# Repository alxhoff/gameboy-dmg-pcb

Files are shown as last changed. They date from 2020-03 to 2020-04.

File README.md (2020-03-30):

# Gameboy DMG Raspberry Pi Board

My revived Corona project, work in progress. The idea of this board is to be a single board drop in for the Gameboy DMG case that is readily availble from all the normal places (eBay, AliExpress etc.) to provide easy game emulation using a Raspberry Pi Zero with distros such as RetroPie. The whole style of the board is that the PCB itself is self explanitory and doesn't require you to go through the schematics, something almost anyone with a bit of soldering knowledge can put together. Many features of the board can be enabled/disabled or changed using the many solder jumper pads.

The board is made in two variants:

- A cheaper to produce <100mm x <100mm board that can be very cheaply produced from manufactureres such as [JLC](https://jlcpcb.com/) and [PCBWay](https://www.pcbway.com).
- A full size (complete case utilization) board that places everything on the same motherboard

# Common components to both implementation

Both boards implement the core required features for creating a portable handheld device. The big difference is that the full size board can make use of the power switches and case cutouts that are more than 100mm from the bottom of the case, as well as being able to place the screen on the motherboard and not require a screen breakout to be used.

## Lipo charger and boost converter

The core component of a handheld device is that is can be battery powered. As such, and to avoid using prefab shields, the board has an onboard Lipo charger and battery protection that then feeds a boost converter to provide the rest of the board with the required 5V to power the RPi, screen and audio.

The Lipo charger is based around a TP4056 charger and a FS312F-G & FS8205 protection IC combo, this feeds the MT3608 boost converter. The board has two through hole battery connections where a standard single cell 4.2v Lipo battery should be connected. The front side of the PCB also has charging status SMD LEDs that can be optionally connected by jumping the appropriate jumper.

## Buttons

The board uses the standard default button layout of the Gameboy DMG also providing eight extra button connections that can be made use of through the through hole connections. The buttons are to connectied to the RPi through an MCP23017 GPIO expander, for which I will write a Linux kernel driver once the hardware is complete, it will be linked here once I am done.

## Audio

The board utilizes the PWM audio output of the RPi, providing both a simple low-pass RC filter as well as a 2.5W mono audio amplifier so that the board can actually produce a decent, and audiable, sound output. A compatible speaker 29mm 0.25W speaker should be attached to the appropriate through hole connectors.

## Screen breakout

The board utilizes the 240 x 320 ILI9341 TFT screens which are a breeze to use with Raspberry Pis through framebuffer copy drivers, such as [this](https://github.com/juj/fbcp-ili9341) one. The smaller board provides a through hole breakout where you can connect, via ribbon cable, the screen's breakout board. I am using a 2.4" screen which requires no modification to the case but larger screens can be placed with minimal modification to the case, these breakouts are available on the larger board, connecting the ribbon cable directly to the board. The larger board uses an elongated footprint to give you complete freedom as to where you solder the board along the horizonal axis.

### Small board

The small PCB provides an exact copy of the pinout found on the common LCD breakout boards such as [3.2" MSP3218](http://www.lcdwiki.com/3.2inch_SPI_Module_ILI9341_SKU:MSP3218), [2.8" MSP2807](http://www.lcdwiki.com/2.8inch_SPI_Module_ILI9341_SKU:MSP2807), [2.4" MSP2402](http://www.lcdwiki.com/2.4inch_SPI_Module_ILI9341_SKU:MSP2402), and [2.2" MSP2202](http://www.lcdwiki.com/2.2inch_SPI_Module_ILI9341_SKU:MSP2202). 

These common breakouts also provide a NPN transisor current driver circuit that allow for PWM control on the backlight. The larger board has this on the motherboard.

| Function | Header Pin | 
| --- |:---:|
| MISO | 1 | 
| BACKLIGHT/LED | 2 |  
| SCK | 3 | 
| MOSI | 4 |
| DC | 5 |
| RESET | 6 |
| CS | 7 |
| GND | 8 |
| 3.3V | 9 |

### Large board

The large board uses a header for the ribbon cable to be connected directly. The pinout is as follows. Also see the [relevant](http://www.lcdwiki.com/res/MSP3218/QD-TFT3202%20specification_v1.1.pdf) datasheets for the pinout

| Function | Header Pin | 
| --- |:---:|
| GND | 1 | 
| RESET | 2 |  
| SCK | 3 | 
| DC | 4 |
| CS | 5 |
| MOSI | 6 |
| MISO | 7 |
| GND | 8 |
| 3.3V | 9 |
| BACKLIGHT LED Anode | 10 |
| BACKLIGHT LED Cathode | 11 - 14|

# Small board

The small board must provide headers for items that are found outside of the PCB's bounds, such as power switch, power LED etc. All of the headers should be labelled as to what they do.

There are a number of labeled jumpers that enable/disable functionality of external parts such as disabling the external power switch by bridging the boost supply's outbut stright to the 5V rail.

The following jumpers can be found on the board.

| Name |Reference | Description | Default State | Notes & WARNINGS!|
| --- |:---:|---|:---:| ----- |
| Charging LEDs | JP11 | Enables the two onboard SMD LEDs that provide the status of charging from the TP4056 charger | Open |
| Connect Boost  | JP9 | Connects the battery charger/battery to the boost charger that then supplies the 5V rail | Open |
| Power switch  | JP8 | Shorts out the power switch, making the boost supply and the 5V rail always connected  | Open |
| Volume potentiometer  | JP10 & JP14 | Will fix the audio input to the PAM8302 audio amp to the differential signal between the LP audio filter's output and ground, removing ability to control volume in hardware| Open |
| PAM8302 Supply 3.3V  | JP12 | Allows for the powering of the audio amplifier from 3.3V instead of the default 5V | Open |
| PAM8302 Supply 3.3V  | JP13 | Allows for the disconnecting of the audio amplifier from its default 5V supply | Closed | NEVER should both jumpers be connects and the device powered |
| GPIO Expander I2C  | JP2 - JP4 | The GPIO expander responsible for the onboard Gameboy buttons is by default not attached to the RPi | Open |
| TFT Backlight  | JP6 & JP7 | The backlight for the LCD can be either driven by the GPIO pins (allowing PWM) or from a constant 3.3V rail, By default the screen is driven from the 3.3V rail, thus disabling PWM capabilities of the FB driver | Open & Closer respectivley | Both pins shouldn't be connected at the same time |
| RPi Audio Out  | JP1 | By default the PWM audio output of the PRi's GPIO 13 is not connected to the audio pre-amp, amp and speaker, this must be enabled by the user | Open |

# Large board

todo

## RPi header

The RPi Zero connects directly to the PCB, enough said :P

# TODO

Large board needs to be branched from small board once it is finished

## Small board/both

- Before first fab check micro USB placement.
- Expand board to provide mounting holdes for 2.4" TFT breakout.

## Large board

- Horizontal power switch in to fit the native power switch at the top of the device.
- Horizontal trim pot placement to make use of the existing screen contrast cutout.
- Screen placement to support 2.4", 2.8" and 3.2" screens.

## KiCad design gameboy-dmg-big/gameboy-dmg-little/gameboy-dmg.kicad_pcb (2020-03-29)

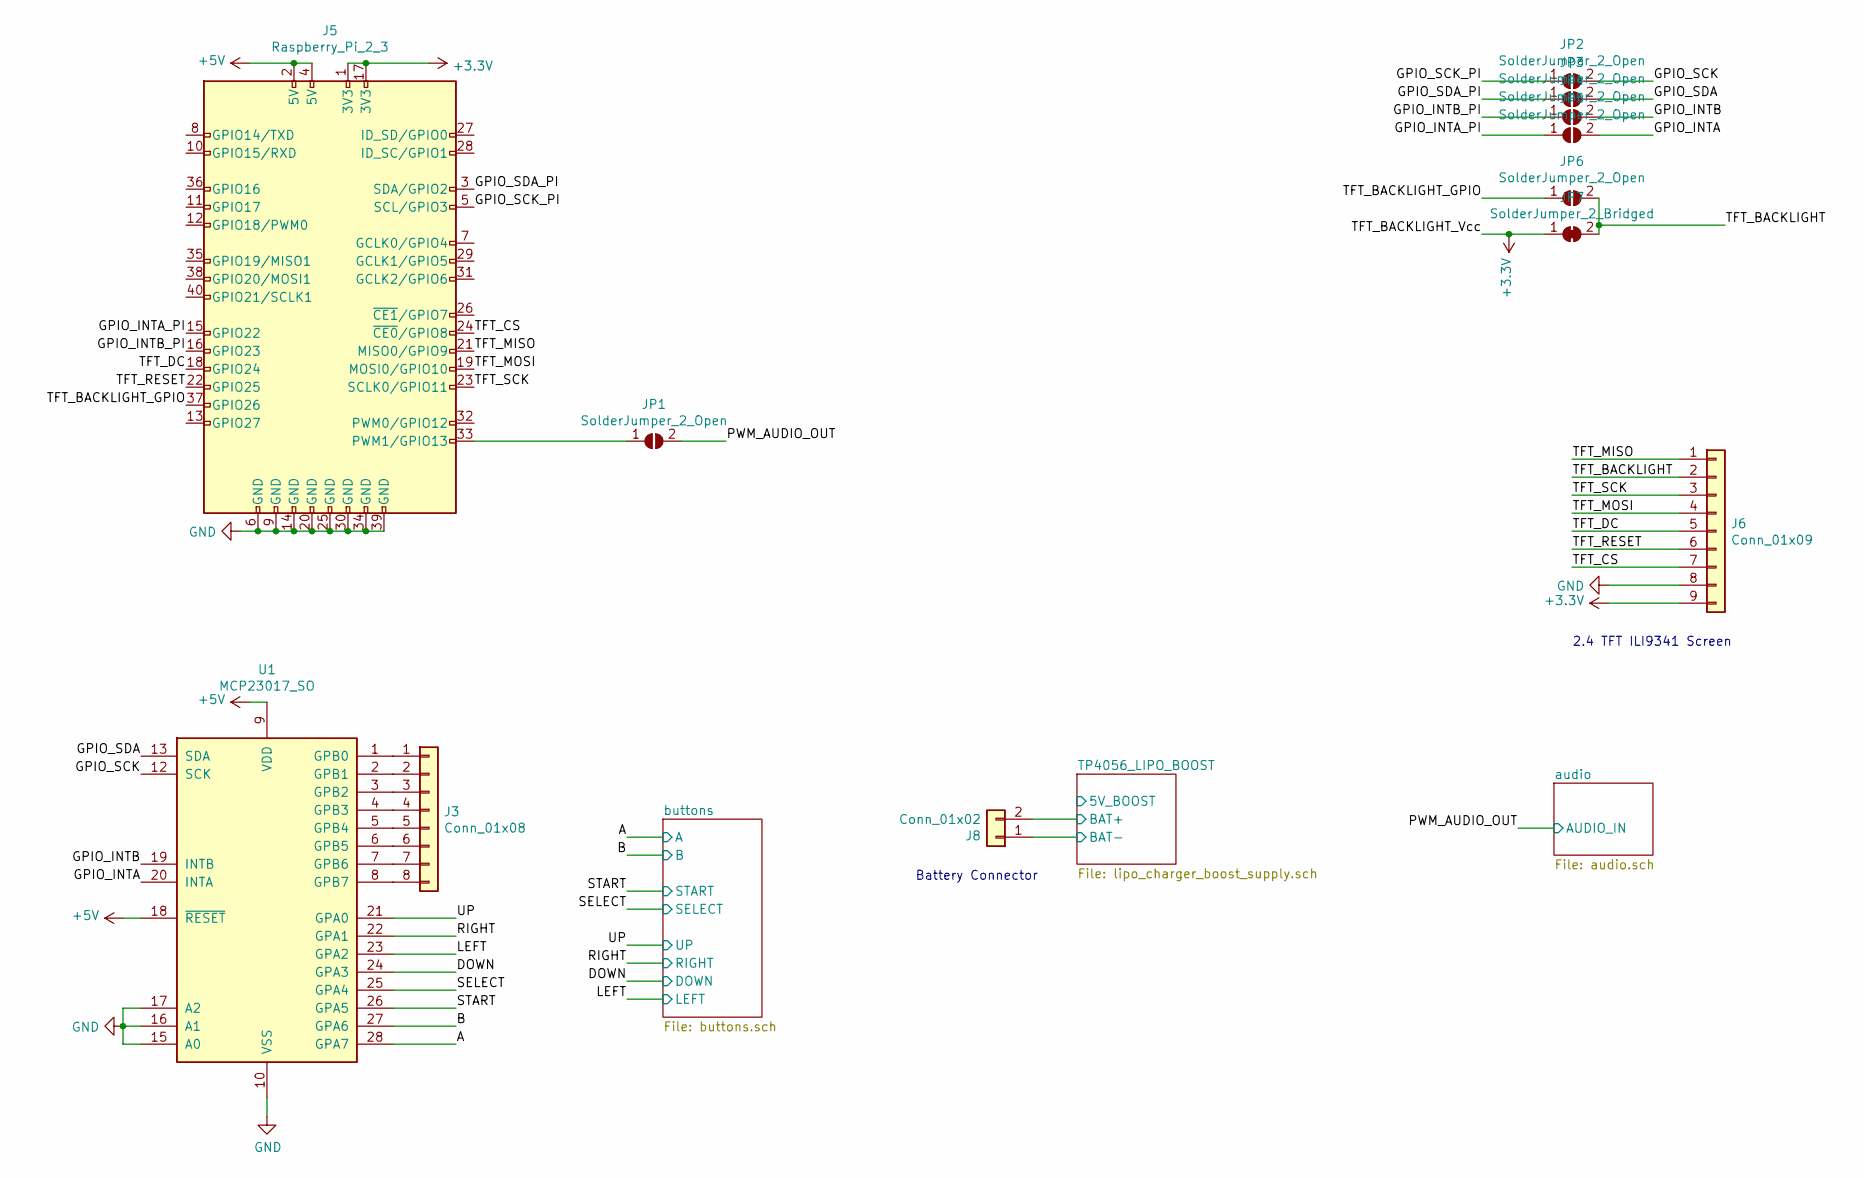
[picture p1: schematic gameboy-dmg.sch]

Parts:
J3: Conn_01x08; PinHeader_1x08_P2.54mm_Vertical
J5: Raspberry_Pi_2_3; PinHeader_2x20_P2.54mm_Vertical
J6: Conn_01x09; PinHeader_1x09_P2.54mm_Vertical
J8: Conn_01x02; PinHeader_1x02_P2.54mm_Vertical
JP1, JP2, JP3, JP4, JP5, JP6: SolderJumper_2_Open; SolderJumper-2_P1.3mm_Open_RoundedPad1.0x1.5mm
JP7: SolderJumper_2_Bridged; SolderJumper-2_P1.3mm_Bridged_RoundedPad1.0x1.5mm
U1: MCP23017_SO; SOIC-28W_7.5x17.9mm_P1.27mm

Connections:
+3V3: J5.1 (3V3), J5.17 (3V3), J6.9, JP7.1 (A); also elsewhere on the board
+5V: J5.2 (5V), J5.4 (5V), U1.9 (VDD), U1.18 (~RESET~); also elsewhere on the board
/A: U1.28 (GPA7); also elsewhere on the board
/B: U1.27 (GPA6); also elsewhere on the board
/DOWN: U1.24 (GPA3); also elsewhere on the board
/GPIO_INTA: JP5.2 (B), U1.20 (INTA)
/GPIO_INTA_PI: J5.15 (GPIO22), JP5.1 (A)
/GPIO_INTB: JP4.2 (B), U1.19 (INTB)
/GPIO_INTB_PI: J5.16 (GPIO23), JP4.1 (A)
/GPIO_SCK: JP2.2 (B), U1.12 (SCK)
/GPIO_SCK_PI: J5.5 (SCL/GPIO3), JP2.1 (A)
/GPIO_SDA: JP3.2 (B), U1.13 (SDA)
/GPIO_SDA_PI: J5.3 (SDA/GPIO2), JP3.1 (A)
/LEFT: U1.23 (GPA2); also elsewhere on the board
/PWM_AUDIO_OUT: JP1.2 (B); also elsewhere on the board
/RIGHT: U1.22 (GPA1); also elsewhere on the board
/SELECT: U1.25 (GPA4); also elsewhere on the board
/START: U1.26 (GPA5); also elsewhere on the board
/TFT_BACKLIGHT: J6.2, JP6.2 (B), JP7.2 (B)
/TFT_BACKLIGHT_GPIO: J5.37 (GPIO26), JP6.1 (A)
/TFT_CS: J5.24 (~CE0~/GPIO8), J6.7
/TFT_DC: J5.18 (GPIO24), J6.5
/TFT_MISO: J5.21 (MISO0/GPIO9), J6.1
/TFT_MOSI: J5.19 (MOSI0/GPIO10), J6.4
/TFT_RESET: J5.22 (GPIO25), J6.6
/TFT_SCK: J5.23 (SCLK0/GPIO11), J6.3
/TP4056_LIPO_BOOST/BAT+: J8.2; also elsewhere on the board
/TP4056_LIPO_BOOST/BAT-: J8.1; also elsewhere on the board
/UP: U1.21 (GPA0); also elsewhere on the board
GND: J5.6 (GND), J5.9 (GND), J5.14 (GND), J5.20 (GND), J5.25 (GND), J5.30 (GND), J5.34 (GND), J5.39 (GND), J6.8, U1.10 (VSS), U1.15 (A0), U1.16 (A1), U1.17 (A2); also elsewhere on the board
unnamed: J3.1, U1.1 (GPB0)
unnamed: J3.2, U1.2 (GPB1)
unnamed: J3.3, U1.3 (GPB2)
unnamed: J3.4, U1.4 (GPB3)
unnamed: J3.5, U1.5 (GPB4)
unnamed: J3.6, U1.6 (GPB5)
unnamed: J3.7, U1.7 (GPB6)
unnamed: J3.8, U1.8 (GPB7)
unnamed: J5.33 (PWM1/GPIO13), JP1.1 (A)

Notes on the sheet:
2.4 TFT ILI9341 Screen
Battery Connector

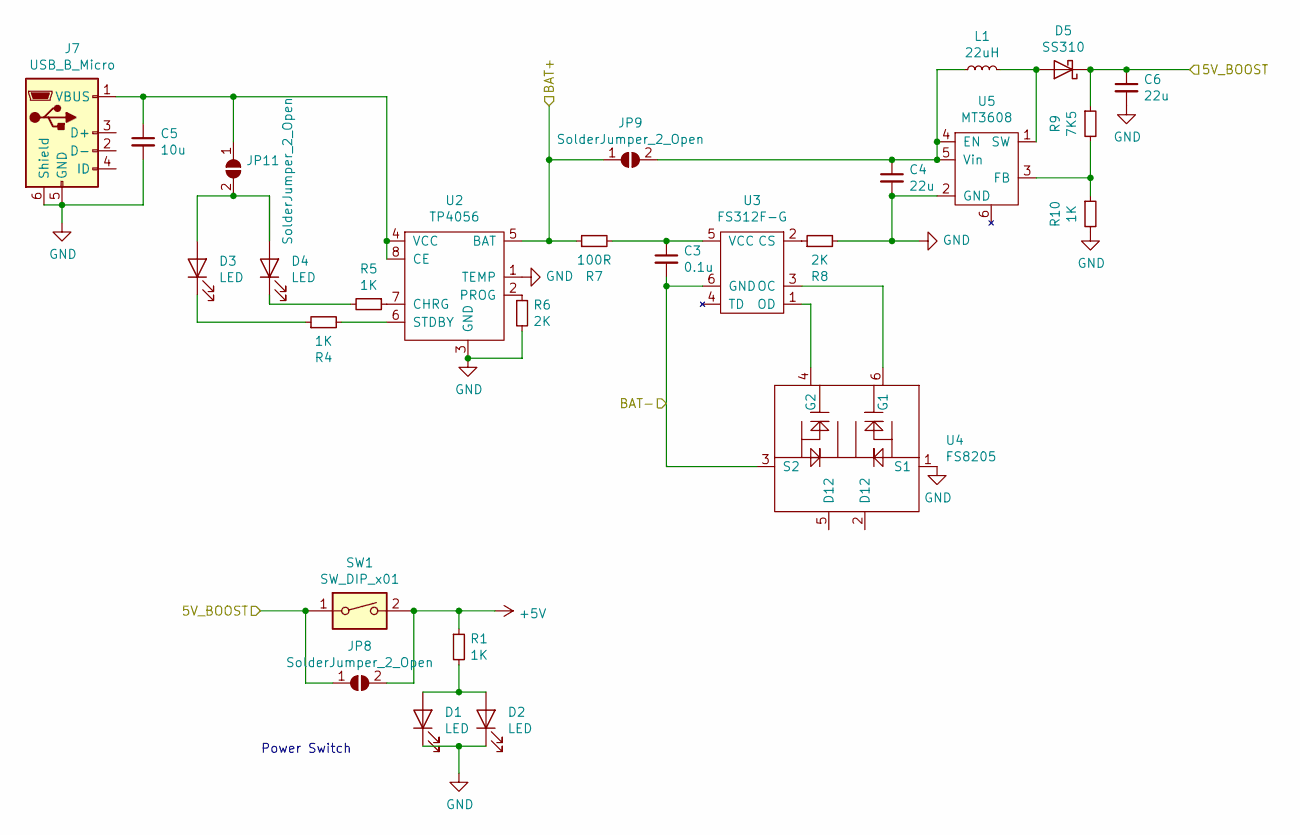
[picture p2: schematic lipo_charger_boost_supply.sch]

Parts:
C3: 0.1u; C_0603_1608Metric
C4, C6: 22u; C_1210_3225Metric
C5: 10u; C_0603_1608Metric
D1, D3, D4: LED; LED_0603_1608Metric
D2: LED; LED_D3.0mm
D5: SS310; D_SMA
J7: USB_B_Micro; USB_Micro-B_Molex-105017-0001
JP8, JP9, JP11: SolderJumper_2_Open; SolderJumper-2_P1.3mm_Open_RoundedPad1.0x1.5mm
L1: 22uH; L_7.3x7.3_H3.5
R1, R4, R5, R10: 1K; R_0603_1608Metric
R6, R8: 2K; R_0603_1608Metric
R7: 100R; R_0603_1608Metric
R9: 7K5; R_0603_1608Metric
SW1: SW_DIP_x01; PinHeader_1x02_P2.54mm_Vertical
U2: TP4056; SOP-8_3.9x4.9mm_P1.27mm
U3: FS312F-G; SOT-23-6
U4: FS8205; SOT-23-6
U5: MT3608; SOT-23-6

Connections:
+5V: JP8.2 (B), R1.1, SW1.2; also elsewhere on the board
/TP4056_LIPO_BOOST/5V_BOOST: C6.1, D5.1 (K), JP8.1 (A), R9.1, SW1.1
/TP4056_LIPO_BOOST/BAT+: JP9.1 (A), R7.1, U2.5 (BAT); also elsewhere on the board
/TP4056_LIPO_BOOST/BAT-: C3.2, U3.6 (GND), U4.3 (S2); also elsewhere on the board
GND: C4.2, C5.2, C6.2, D1.1 (K), D2.1 (K), J7.5 (GND), J7.6 (Shield), R6.2, R8.2, R10.2, U2.1 (TEMP), U2.3 (GND), U4.1 (S1), U5.2 (GND); also elsewhere on the board
unnamed: C3.1, R7.2, U3.5 (VCC)
unnamed: C4.1, JP9.2 (B), L1.1, U5.4 (EN), U5.5 (Vin)
unnamed: C5.1, J7.1 (VBUS), JP11.1 (A), U2.4 (VCC), U2.8 (CE)
unnamed: D1.2 (A), D2.2 (A), R1.2
unnamed: D3.1 (K), R4.1
unnamed: D3.2 (A), D4.2 (A), JP11.2 (B)
unnamed: D4.1 (K), R5.2
unnamed: D5.2 (A), L1.2, U5.1 (SW)
unnamed: R4.2, U2.6 (STDBY)
unnamed: R5.1, U2.7 (CHRG)
unnamed: R6.1, U2.2 (PROG)
unnamed: R8.1, U3.2 (CS)
unnamed: R9.2, R10.1, U5.3 (FB)
unnamed: U3.1 (OD), U4.4 (G2)
unnamed: U3.3 (OC), U4.6 (G1)

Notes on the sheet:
Power Switch

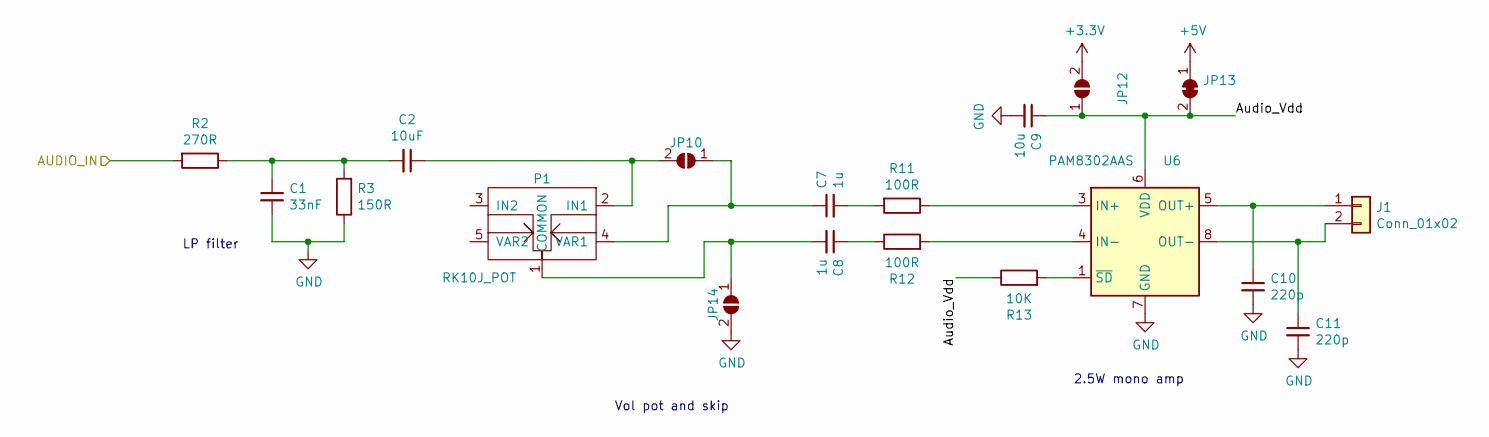
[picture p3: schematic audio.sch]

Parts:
C1: 33nF; C_0603_1608Metric
C2: 10uF; CP_Radial_D5.0mm_P2.00mm
C7, C8: 1u; C_0603_1608Metric
C9: 10u; C_0603_1608Metric
C10, C11: 220p; C_0603_1608Metric
J1: Conn_01x02; PinHeader_1x02_P2.54mm_Vertical
JP10, JP12, JP14: SolderJumper_2_Open; SolderJumper-2_P1.3mm_Open_RoundedPad1.0x1.5mm
JP13: SolderJumper_2_Bridged; SolderJumper-2_P1.3mm_Bridged_RoundedPad1.0x1.5mm
P1: RK10J_POT; R503_POT
R2: 270R; R_0603_1608Metric
R3: 150R; R_0603_1608Metric
R11, R12: 100R; R_0603_1608Metric
R13: 10K; R_0603_1608Metric
U6: PAM8302AAS; MSOP-8_3x3mm_P0.65mm

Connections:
+3V3: JP12.2 (B); also elsewhere on the board
+5V: JP13.1 (A); also elsewhere on the board
/PWM_AUDIO_OUT: R2.2; also elsewhere on the board
/audio/Audio_Vdd: C9.1, JP12.1 (A), JP13.2 (B), R13.1, U6.6 (VDD)
GND: C1.2, C9.2, C10.2, C11.2, JP14.2 (B), R3.1, U6.7 (GND); also elsewhere on the board
unnamed: C1.1, C2.2, R2.1, R3.2
unnamed: C2.1, JP10.2 (B), P1.2 (IN1)
unnamed: C7.1, JP10.1 (A), P1.4 (VAR1)
unnamed: C7.2, R11.2
unnamed: C8.1, R12.1
unnamed: C8.2, JP14.1 (A), P1.1 (COMMON)
unnamed: C10.1, J1.1, U6.5 (OUT+)
unnamed: C11.1, J1.2, U6.8 (OUT-)
unnamed: R11.1, U6.3 (IN+)
unnamed: R12.2, U6.4 (IN-)
unnamed: R13.2, U6.1 (~SD)

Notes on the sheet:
Vol pot and skip
LP filter
2.5W mono amp

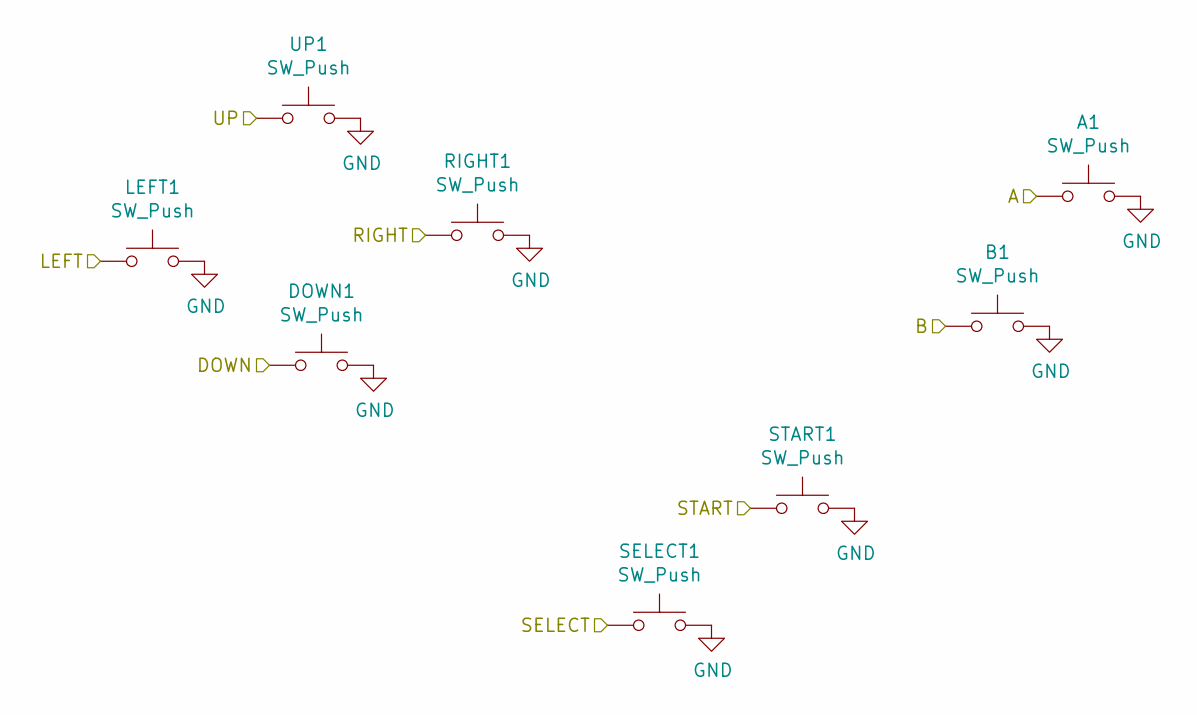
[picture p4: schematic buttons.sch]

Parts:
A1: SW_Push; GAMEBOY_BUTTON_PAD-D6MM
B1: SW_Push; GAMEBOY_BUTTON_PAD-D6MM
DOWN1: SW_Push; GAMEBOY_BUTTON_PAD-D6MM
LEFT1: SW_Push; GAMEBOY_BUTTON_PAD-D6MM
RIGHT1: SW_Push; GAMEBOY_BUTTON_PAD-D6MM
SELECT1: SW_Push; GAMEBOY_BUTTON_PAD-DUAL_D4MM
START1: SW_Push; GAMEBOY_BUTTON_PAD-DUAL_D4MM
UP1: SW_Push; GAMEBOY_BUTTON_PAD-D6MM

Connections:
/A: A1.1; also elsewhere on the board
/B: B1.1; also elsewhere on the board
/DOWN: DOWN1.1; also elsewhere on the board
/LEFT: LEFT1.1; also elsewhere on the board
/RIGHT: RIGHT1.1; also elsewhere on the board
/SELECT: SELECT1.1; also elsewhere on the board
/START: START1.1; also elsewhere on the board
/UP: UP1.1; also elsewhere on the board
GND: A1.2, B1.2, DOWN1.2, LEFT1.2, RIGHT1.2, SELECT1.2, START1.2, UP1.2; also elsewhere on the board

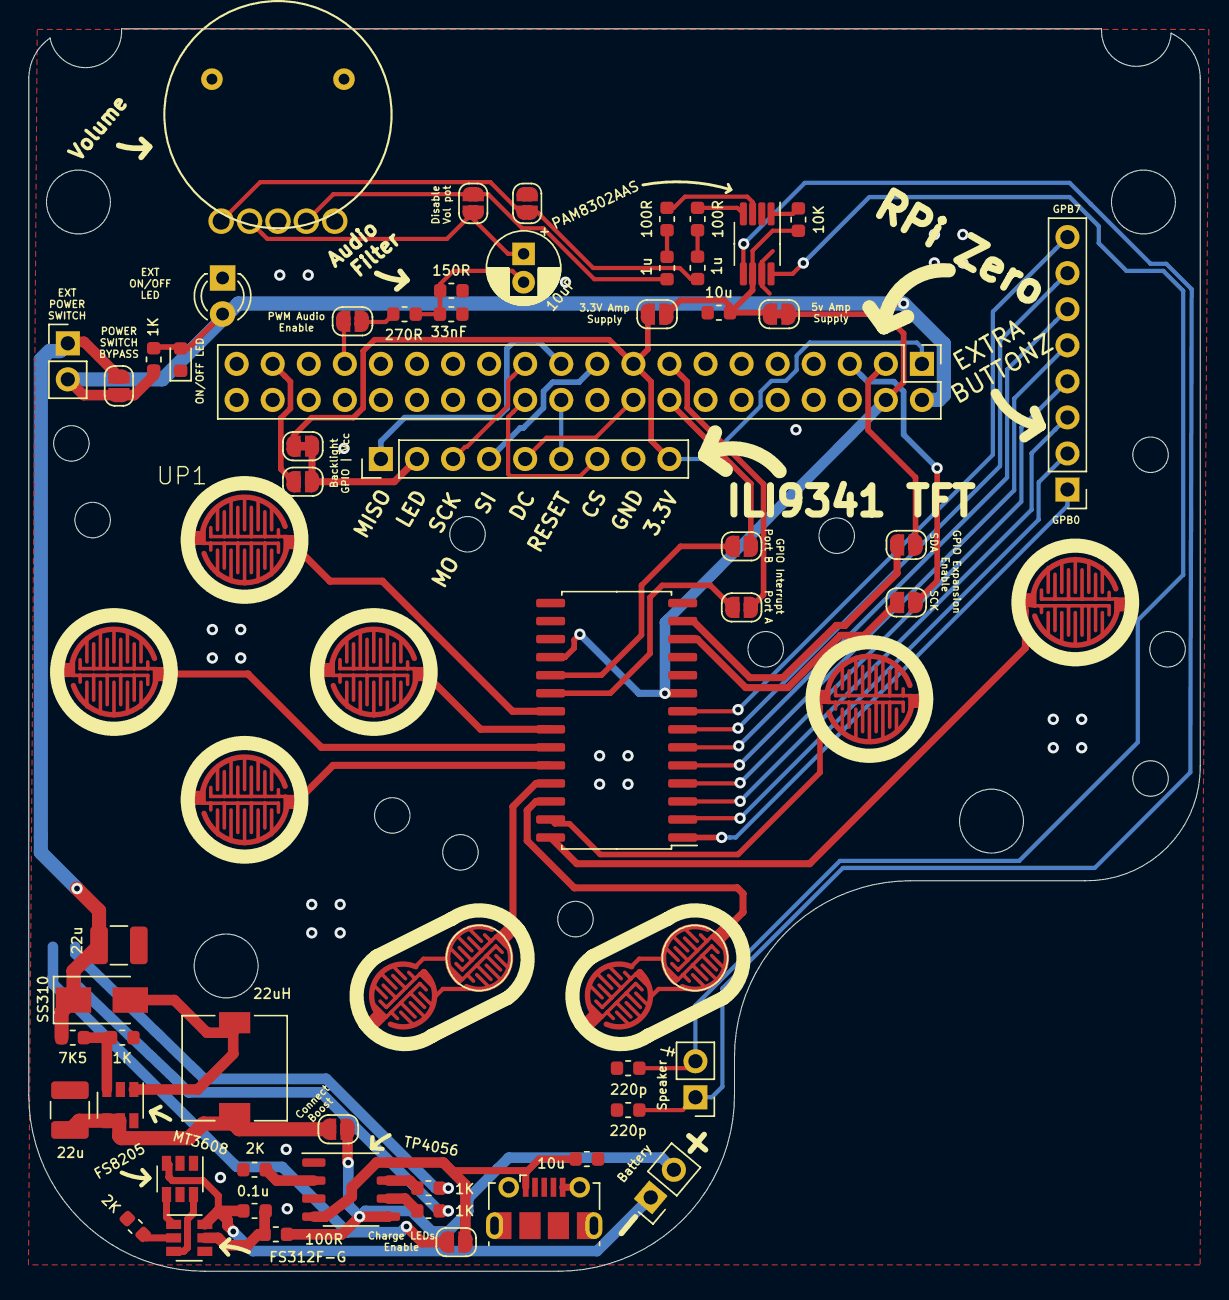
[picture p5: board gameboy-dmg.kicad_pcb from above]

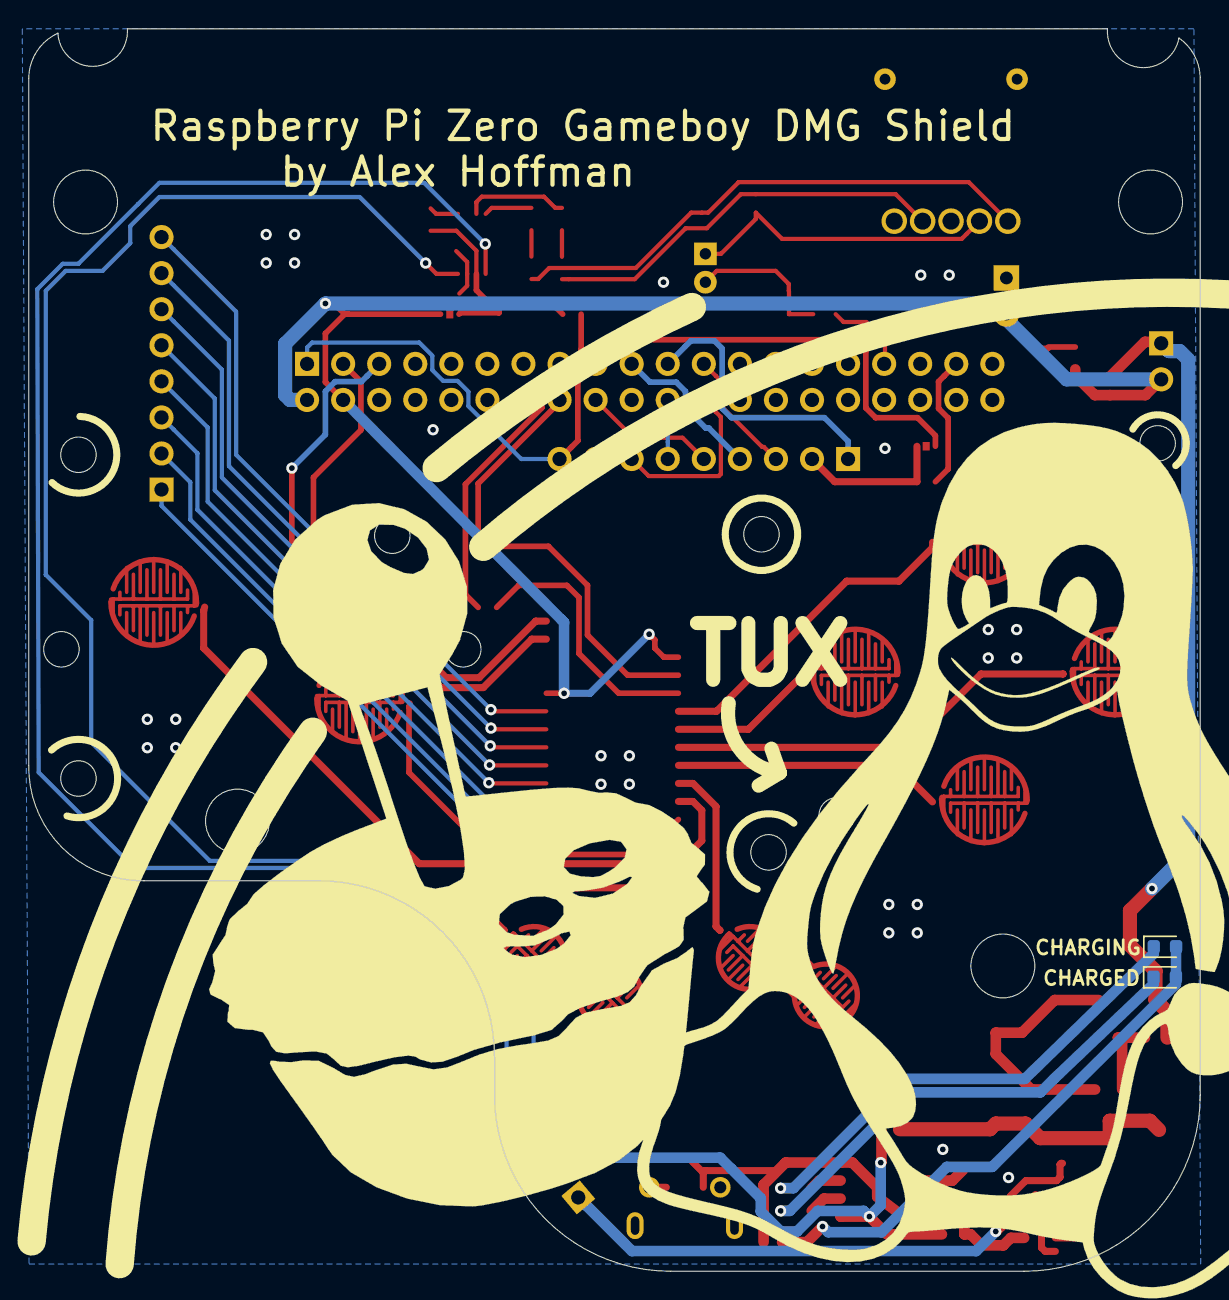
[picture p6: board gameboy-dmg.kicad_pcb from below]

Board: 2 copper layers, 82.5 x 87.5 mm, 66 parts (2 on the bottom side), 67 nets.

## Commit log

2020-03-27 Initial PCB idea
    [gameboy-dmg.kicad_pcb, gameboy-dmg.sch]
2020-03-27 Added some graphics and stuffs
    [gameboy-dmg.kicad_pcb, gameboy-dmg.sch]
2020-03-27 Added some more bits
    [gameboy-dmg.kicad_pcb, gameboy-dmg.sch]
2020-03-27 Fixed some missing holes
    [gameboy-dmg.kicad_pcb, gameboy-dmg.sch]
2020-03-28 Rough lipo charger and 5v boost added
    [gameboy-dmg.kicad_pcb, gameboy-dmg.sch, lipo_charger_boost_supply.sch]
2020-03-28 Broke out all of port B to extenal pins from the MSP GPIO expander
    [gameboy-dmg.kicad_pcb, gameboy-dmg.sch]
2020-03-28 Cleaning up text
    [gameboy-dmg.kicad_pcb]
2020-03-29 Moved buttons and audio to individual sheets and added audio amp
    [audio.sch, buttons.sch, gameboy-dmg.kicad_pcb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]
2020-03-29 Added unroputed and unchecked horizontal vol pot
    [audio.sch, gameboy-dmg.kicad_pcb, gameboy-dmg.sch]
2020-03-29 Little board ready for fab
    [gameboy-dmg.kicad_pcb]
2020-03-29 Little board ready for check and fab
    [audio.sch, buttons.sch, gameboy-dmg.kicad_pcb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]
2020-03-30 Added ribbon cable TFT to big and routed it
    [MSP_LCD.sch, audio.sch, buttons.sch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]
2020-03-30 Shifter RPi up
    [gameboy-dmg.kicad_pcb]
2020-03-30 Fixed up little board
    [gameboy-dmg.kicad_pcb]
2020-03-30 Fixed up big board
    [gameboy-dmg.kicad_pcb]
2020-03-30 Big board gerbers
    [MSP_LCD.sch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]
2020-03-30 Little board gerbers
    [gameboy-dmg-B_Cu.gbr, gameboy-dmg-B_Mask.gbr, gameboy-dmg-B_SilkS.gbr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]
2020-03-30 Prototypes 1.0
    [gameboy-dmg-B_Cu.gbr, gameboy-dmg-B_Mask.gbr, gameboy-dmg-B_SilkS.gbr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]
2020-04-17 Updated PCBs from initial debugging
    [gameboy-dmg.kicad_pcb]
